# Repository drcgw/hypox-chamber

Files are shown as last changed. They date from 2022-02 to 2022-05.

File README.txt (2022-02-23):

Initial Raspberry Pi 4 set up

Using the Raspberry Pi OS installer (https://www.raspberrypi.com/software/) and a blank microSD card (128 GB Recommended) write the raspbian OS onto the SD card. Under the "operating system" menu select "Raspberry Pi OS (other)" and select "Raspberry Pi OS Full (32-bit)". Once the operating system is written to the SD card placed into Raspberry Pi. 

Once initial setup is completed go to terminal (Ctrl + T) and run the following codes:
    sudo apt update
    sudo apt full-upgrade

Next step is to download WiringPi:
    sudo apt-get update
    git clone https://github.com/WiringPi/WiringPi
    cd WiringPi
    ./build

Once these applications have been downloaded check the version by running:
    gpio -v
    gpio readall

System settings also need to be modified. Go to the configuration settings by using the following code: 
    sudo raspi-config
    
Under "Interfacing Options" insure that camera, SSH, VNC, SPI, I2C, Serial, and Remote GPIO are all enabled
System will require a reboot following these changes. The final items that need to be installed are all the python packaged and adafruit system requirements for CircuitPython. Tutorials and information can be found on Adafruit's website (https://learn.adafruit.com/welcome-to-circuitpython).
    sudo pip3 install adafruit-circuitpython-ads1x15
    sudo pip3 install adafruit-circuitpython-bme280
    sudo pip3 install adafruit-circuitpython-mcp9808
    sudo pip3 install adafruit-circuitpython-ccs811
    sudo pip3 install adafruit-circuitpython-bh1750

Once all the background files have been downloaded the github library can be downloaded using 
    wget https://github.com/drcgw/hypox-chamber.git

Unpack the files by unzipping and move RunChamber.sh file to the desktop.

Files can also be run manually through the terminal. Move the "PythonScript/" folder under "Documents/". If running manually before each run create a folder under "Documents/" with the following naming format "YYYY-MM-DD-Exposure/". Once inside this directory create: "FinalData/", "RawData/", "Calibration/" & "ImageCapture/" folders. After these folders have been created the exposure code can be run using the follow codes in the terminal. 
	cd Documents/PythonCodes/
	python3 2022-02-15-HC2000.py

If running it manually make sure that the most recent code has been installed and change the name in the second line of the above code to match the most recent copy of the .py script under the PythonCodes folder.

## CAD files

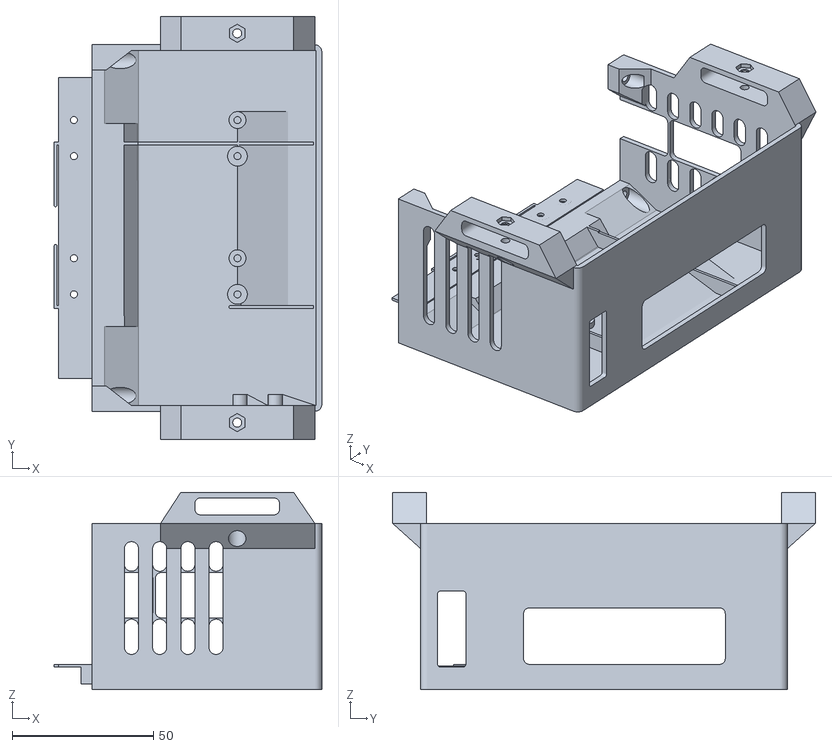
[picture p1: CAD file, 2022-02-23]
3D_Files/RH501_PiHolder_Left.stl
94.9 x 150.0 x 70.0

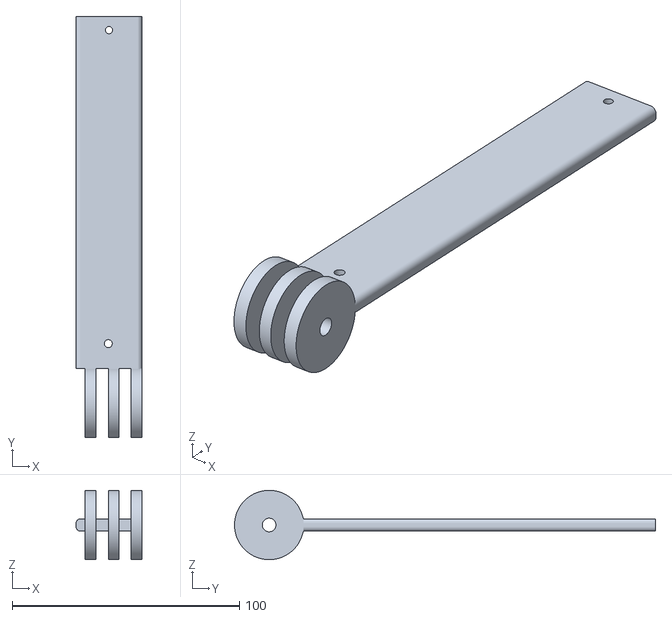
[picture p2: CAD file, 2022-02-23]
3D_Files/RH500_MountingRod.stl
29.0 x 185.3 x 30.5

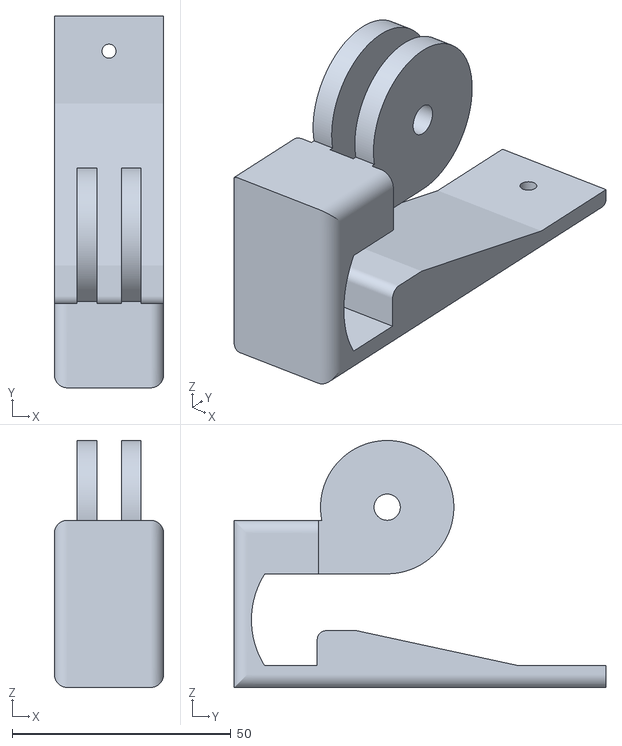
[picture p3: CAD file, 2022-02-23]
3D_Files/RH500_Clip.stl
25.0 x 85.0 x 56.5

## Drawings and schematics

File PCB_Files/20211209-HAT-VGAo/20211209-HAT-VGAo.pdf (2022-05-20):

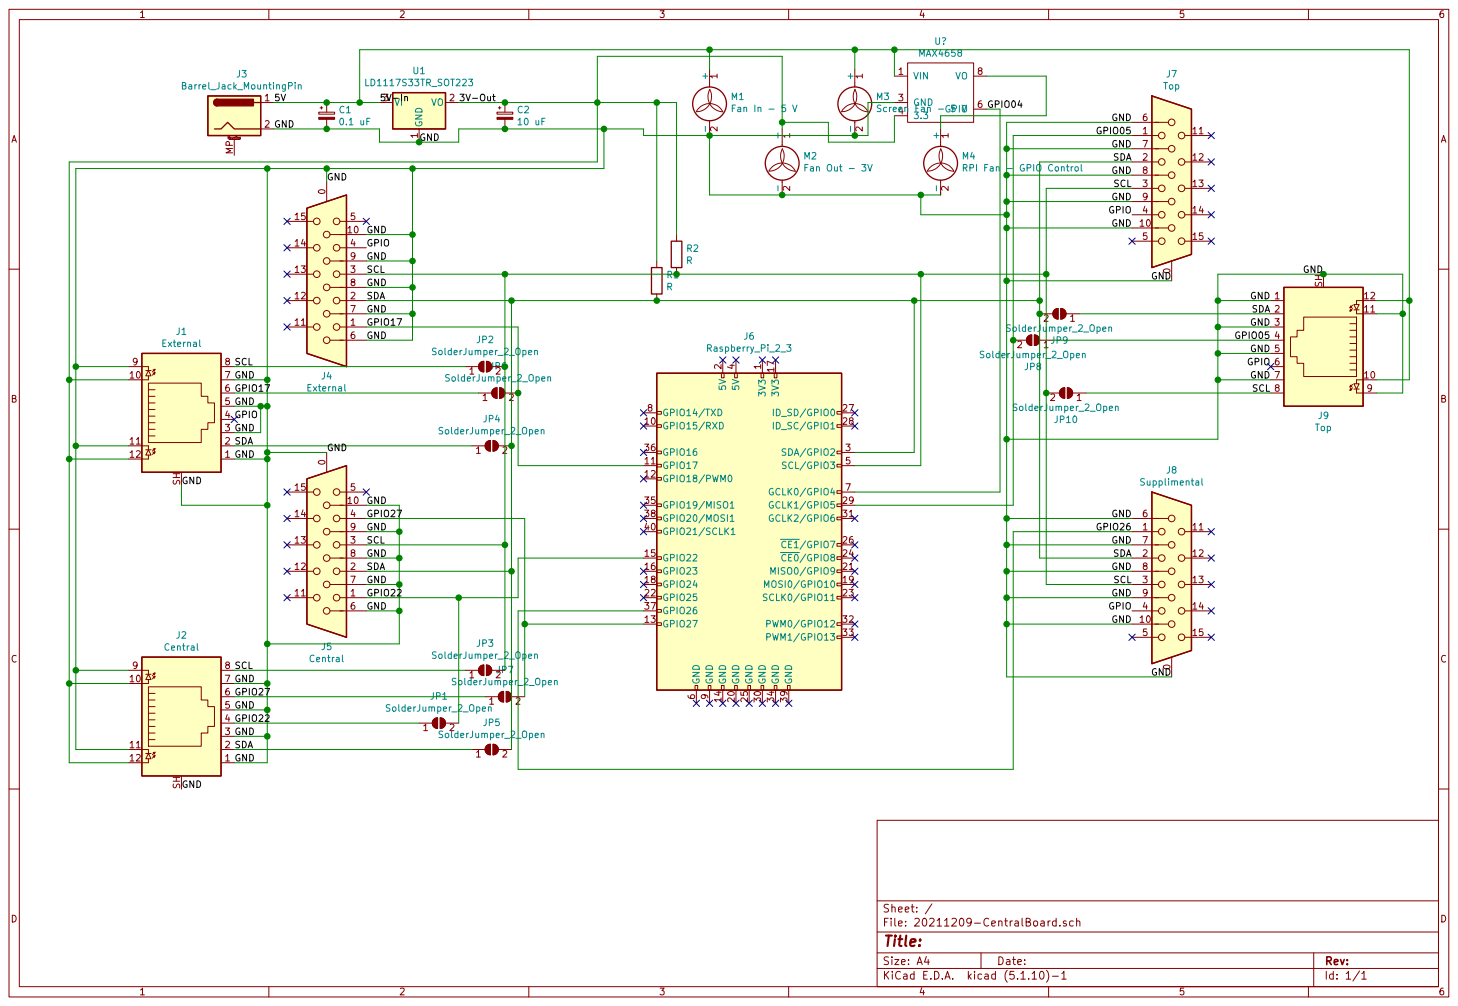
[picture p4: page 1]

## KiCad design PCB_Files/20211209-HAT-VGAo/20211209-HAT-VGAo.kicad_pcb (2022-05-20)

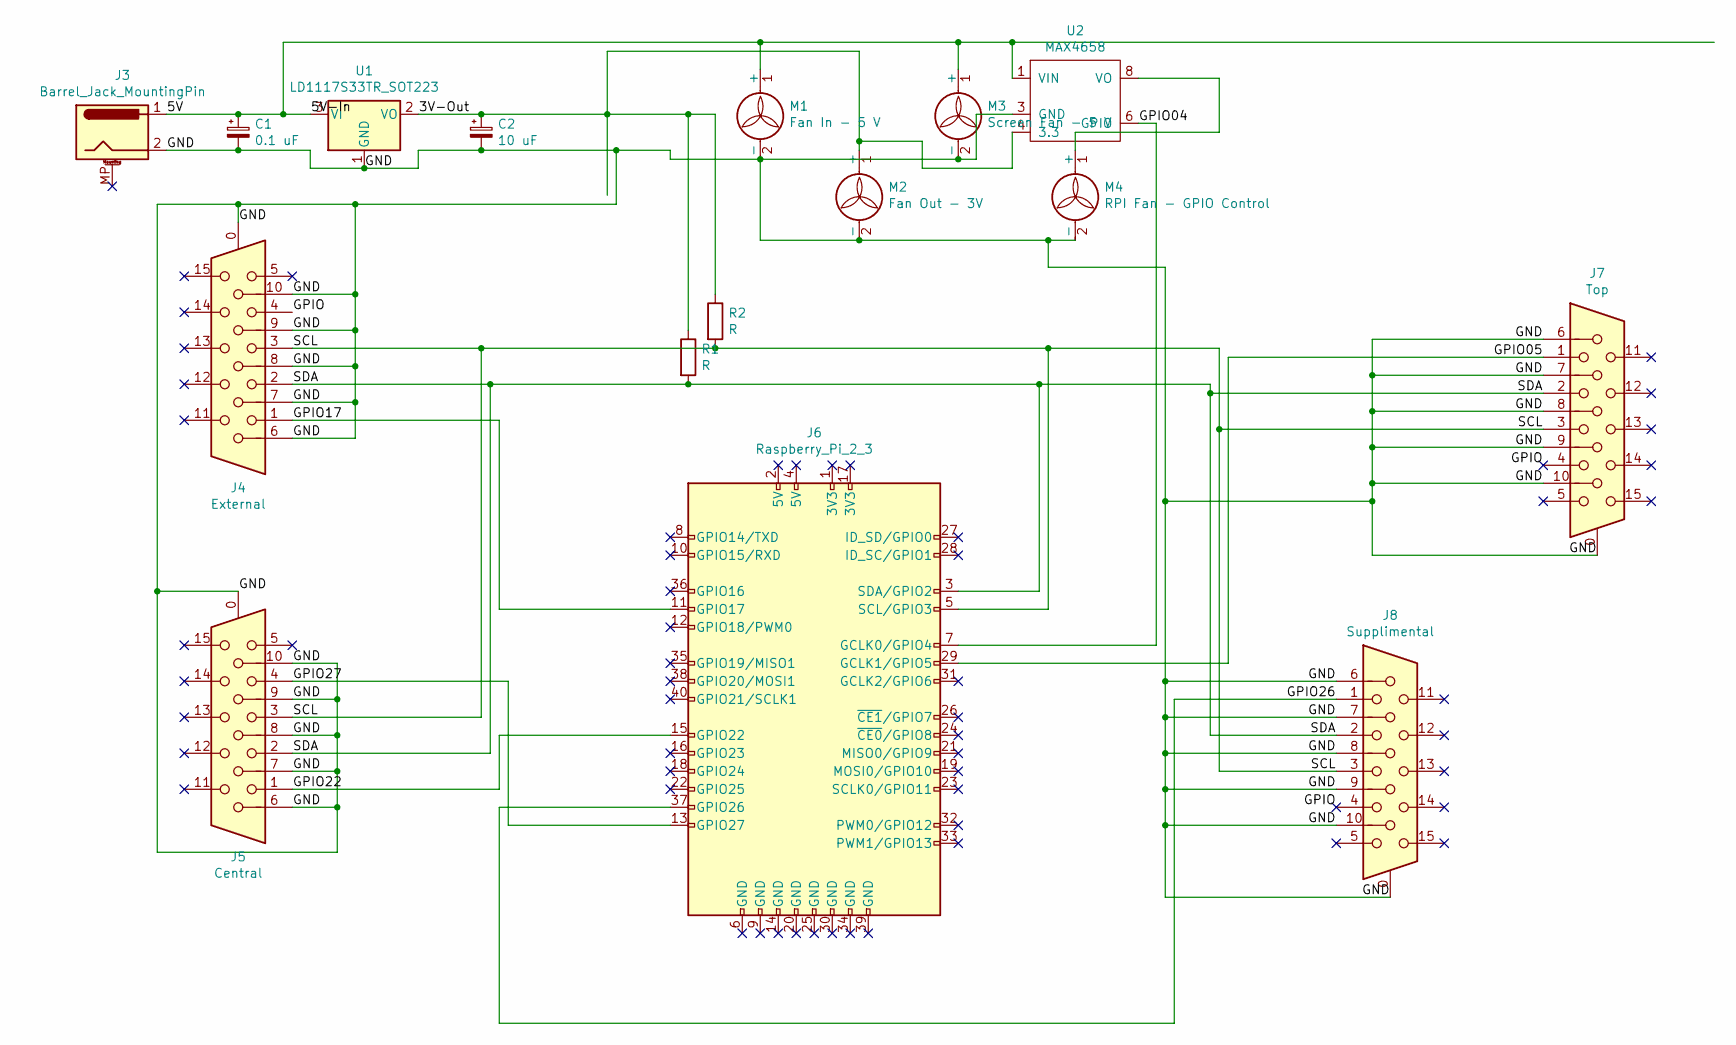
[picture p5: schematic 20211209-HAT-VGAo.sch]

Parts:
C1: 0.1 uF; C_Disc_D3.0mm_W2.0mm_P2.50mm
C2: 10 uF; CP_Radial_D5.0mm_P2.50mm
J3: Barrel_Jack_MountingPin; BarrelJack_Horizontal_w_MP
J4: External; DSUB-15-HD-Female-Horixonal_P2.29x2.54mm_EdgePinOffset8.35m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
J5: Central; DSUB-15-HD-Female-Horixonal_P2.29x2.54mm_EdgePinOffset8.35m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
J6: Raspberry_Pi_2_3; Raspberry_Pi_GPIO_ScrewAttachment
J7: Top; DSUB-15-HD-Female-Horixonal_P2.29x2.54mm_EdgePinOffset8.35m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
J8: Supplimental; DSUB-15-HD-Female-Horixonal_P2.29x2.54mm_EdgePinOffset8.35m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
M1: Fan In - 5 V; PinHeader_1x02_P2.54mm_Vertical (2)
M2: Fan Out - 3V; PinHeader_1x02_P2.54mm_Vertical (2)
M3: Screen Fan - 5 V; PinHeader_1x02_P2.54mm_Vertical (2)
M4: RPI Fan - GPIO Control; RPi_Fan_30mm_24mm
R1, R2: R; R_Axial_DIN0204_L3.6mm_D1.6mm_P7.62mm_Horizontal
U1: LD1117S33TR_SOT223; 3.3V_Regulator
U2: MAX4658

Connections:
/3V-Out: C2.1, M2.1 (+), R1.1, R2.1, U1.2 (VO), U2.4 (3.3)
/5V: C1.1, J3.1, M1.1 (+), M3.1 (+), U1.3 (VI), U2.1 (VIN)
/GND: C1.2, C2.2, J3.2, J4.0, J4.6, J4.7, J4.8, J4.9, J4.10, J5.0, J5.6, J5.7, J5.8, J5.9, J5.10, J7.0, J7.6, J7.7, J7.8, J7.9, J7.10, J8.0, J8.6, J8.7, J8.8, J8.9, J8.10, M1.2 (-), M2.2 (-), M3.2 (-), M4.2 (-), U1.1 (GND), U2.3 (GND)
/GPIO: J4.4, J7.4, J8.4
/GPIO04: J6.7 (GCLK0/GPIO4), U2.6 (GPIO)
/GPIO05: J6.29 (GCLK1/GPIO5), J7.1
/GPIO17: J4.1, J6.11 (GPIO17)
/GPIO22: J5.1, J6.15 (GPIO22)
/GPIO26: J6.37 (GPIO26), J8.1
/GPIO27: J5.4, J6.13 (GPIO27)
/SCL: J4.3, J5.3, J6.5 (SCL/GPIO3), J7.3, J8.3, R2.2
/SDA: J4.2, J5.2, J6.3 (SDA/GPIO2), J7.2, J8.2, R1.2
unnamed: M4.1 (+), U2.8 (VO)

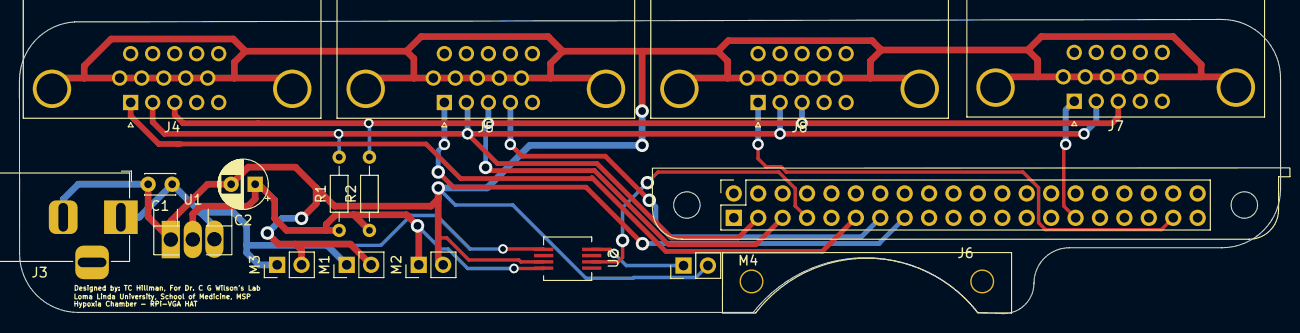
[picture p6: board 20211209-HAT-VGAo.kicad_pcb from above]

Board: 2 copper layers, 131.2 x 30.6 mm, 16 parts (0 on the bottom side), 13 nets.

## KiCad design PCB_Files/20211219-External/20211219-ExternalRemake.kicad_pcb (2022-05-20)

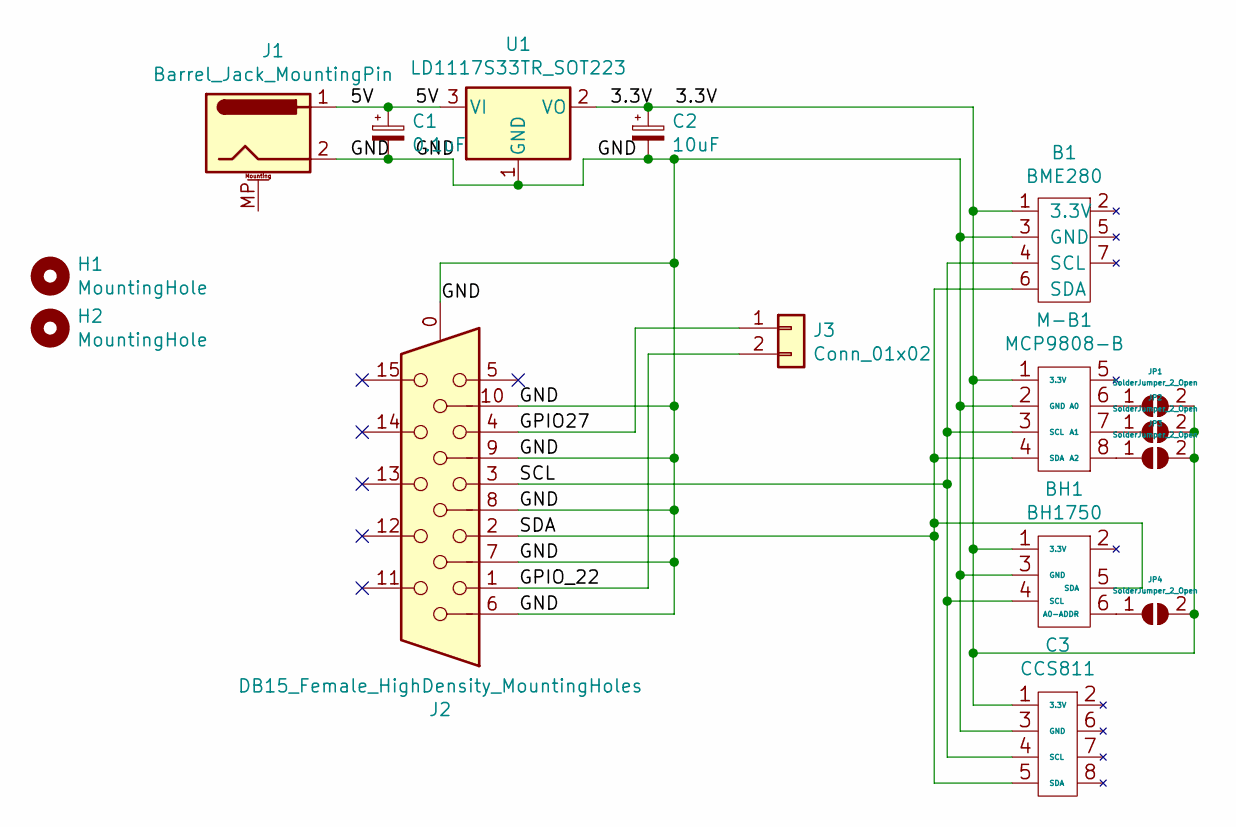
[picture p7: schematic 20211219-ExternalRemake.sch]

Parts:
B1: BME280; PinHeader_1x07_P2.54mm_Vertical
BH1: BH1750; PinHeader_1x06_P2.54mm_Vertical
C1: 0.1uF; C_Disc_D5.1mm_W3.2mm_P5.00mm
C2: 10uF; CP_Radial_D6.3mm_P2.50mm
C3: CCS811; PinHeader_1x08_P2.54mm_Vertical
H1, H2: MountingHole; MountingHole_2.7mm_M2.5_DIN965_Pad_TopBottom
J1: Barrel_Jack_MountingPin; BarrelJack_Horizontal_w_MP
J2: DB15_Female_HighDensity_MountingHoles; DSUB-15-HD-Female-Horixonal_P2.29x2.54mm_EdgePinOffset8.35m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
J3: Conn_01x02; PinHeader_1x02_P2.54mm_Vertical
JP1, JP2, JP3, JP4: SolderJumper_2_Open; SolderJumper-2_P1.3mm_Open_TrianglePad1.0x1.5mm
M-B1: MCP9808-B; PinHeader_1x08_P2.54mm_Vertical
U1: LD1117S33TR_SOT223; 3.3V_Regulator

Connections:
/3.3V: B1.1 (3.3V), BH1.1 (3.3V), C2.1, C3.1 (3.3V), JP1.2 (B), JP2.2 (B), JP3.2 (B), JP4.2 (B), M-B1.1 (3.3V), U1.2 (VO)
/5V: C1.1, J1.1, U1.3 (VI)
/GND: B1.3 (GND), BH1.3 (GND), C1.2, C2.2, C3.3 (GND), J1.2, J2.0, J2.6, J2.7, J2.8, J2.9, J2.10, M-B1.2 (GND), U1.1 (GND)
/GPIO27: J2.4, J3.1
/GPIO_22: J2.1, J3.2
/SCL: B1.4 (SCL), BH1.4 (SCL), C3.4 (SCL), J2.3, M-B1.3 (SCL)
/SDA: B1.6 (SDA), BH1.5 (SDA), C3.5 (SDA), J2.2, M-B1.4 (SDA)
unnamed: BH1.6 (A0-ADDR), JP4.1 (A)
unnamed: JP1.1 (A), M-B1.6 (A0)
unnamed: JP2.1 (A), M-B1.7 (A1)
unnamed: JP3.1 (A), M-B1.8 (A2)

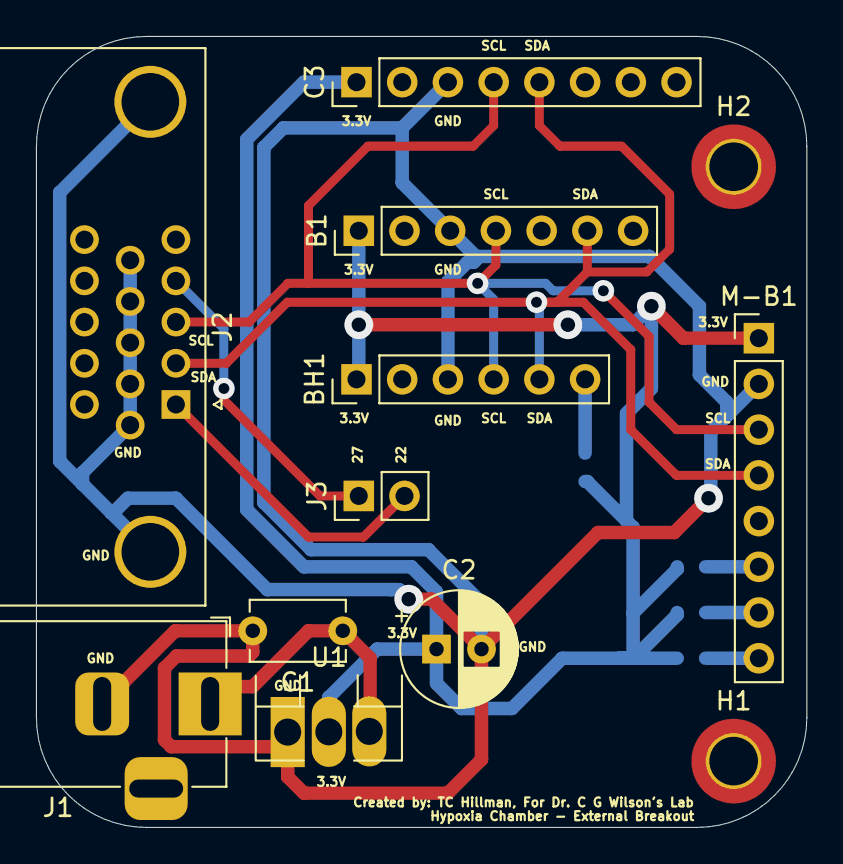
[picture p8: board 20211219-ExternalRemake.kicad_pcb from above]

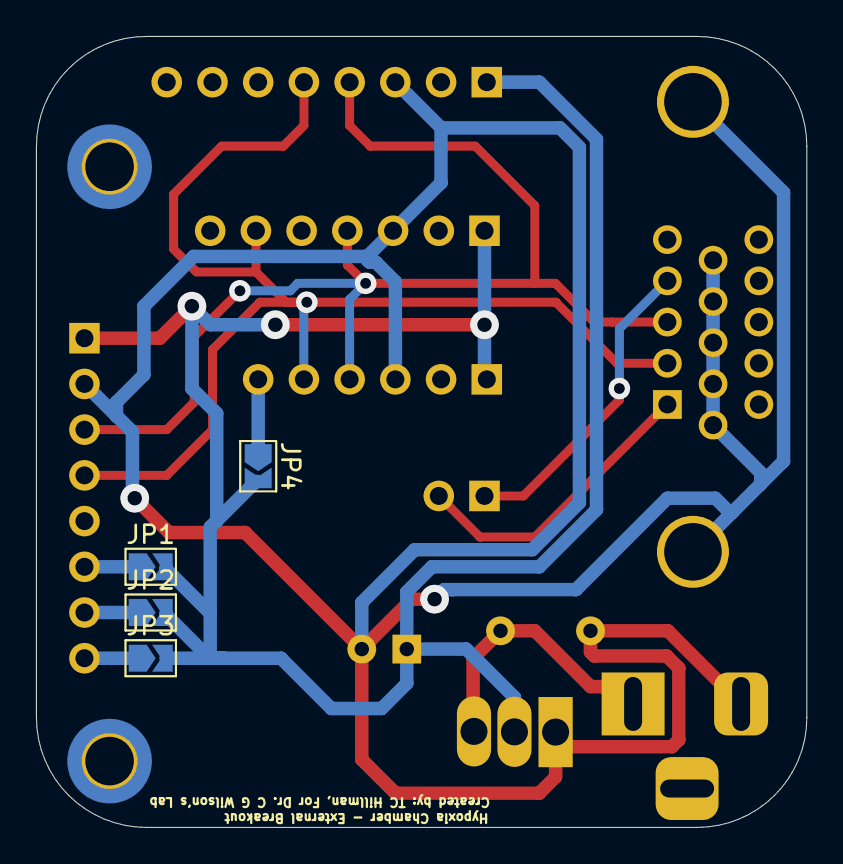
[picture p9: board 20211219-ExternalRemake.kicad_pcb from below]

Board: 2 copper layers, 42.8 x 43.9 mm, 16 parts (4 on the bottom side), 11 nets.

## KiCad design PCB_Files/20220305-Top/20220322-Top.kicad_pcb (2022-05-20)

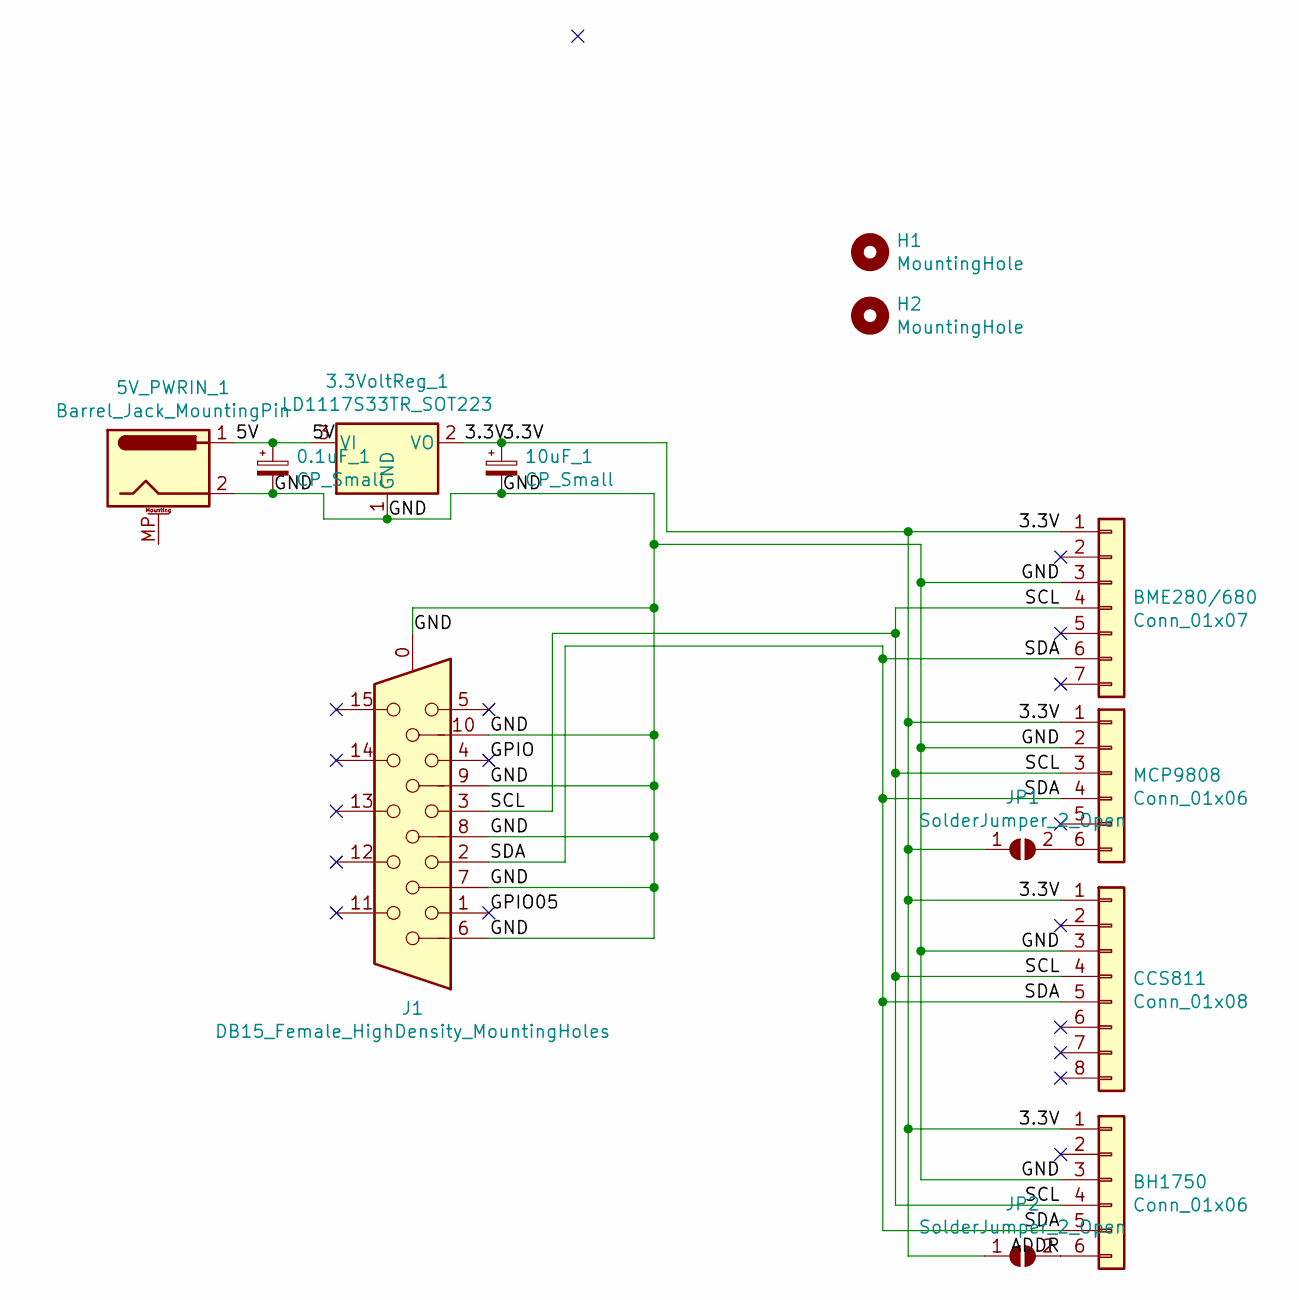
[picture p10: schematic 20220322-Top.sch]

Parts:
0.1uF_1: CP_Small; C_Disc_0.1uF_D3.8mm_W2.6mm_P2.50mm
3.3VoltReg_1: LD1117S33TR_SOT223; 3.3V_Regulator
5V_PWRIN_1: Barrel_Jack_MountingPin; BarrelJack_Horizontal_w_MP
10uF_1: CP_Small; CP_10uF_Radial_D6.3mm_P2.50mm
BH1750: Conn_01x06; PinHeader_1x06_P2.54mm_Vertical
BME280/680: Conn_01x07; PinHeader_1x07_P2.54mm_Vertical
CCS811: Conn_01x08; PinHeader_1x08_P2.54mm_Vertical
H1, H2: MountingHole; MountingHole_2.5mm_Pad_TopBottom
J1: DB15_Female_HighDensity_MountingHoles; DSUB-15-HD-Female-Horixonal_P2.29x2.54mm_EdgePinOffset8.35m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
JP1, JP2: SolderJumper_2_Open; SolderJumper-2_P1.3mm_Open_TrianglePad1.0x1.5mm
MCP9808: Conn_01x06; PinHeader_1x06_P2.54mm_Vertical

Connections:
/3.3V: 3.3VoltReg_1.2 (VO), 10uF_1.1, BH1750.1, BME280/680.1, CCS811.1, JP1.1 (A), JP2.1 (A), MCP9808.1
/5V: 0.1uF_1.1, 3.3VoltReg_1.3 (VI), 5V_PWRIN_1.1
/ADDR: BH1750.6, JP2.2 (B)
/GND: 0.1uF_1.2, 3.3VoltReg_1.1 (GND), 5V_PWRIN_1.2, 10uF_1.2, BH1750.3, BME280/680.3, CCS811.3, J1.0, J1.6, J1.7, J1.8, J1.9, J1.10, MCP9808.2
/GPIO: J1.4
/GPIO05: J1.1
/SCL: BH1750.4, BME280/680.4, CCS811.4, J1.3, MCP9808.3
/SDA: BH1750.5, BME280/680.6, CCS811.5, J1.2, MCP9808.4
unnamed: JP1.2 (B), MCP9808.6

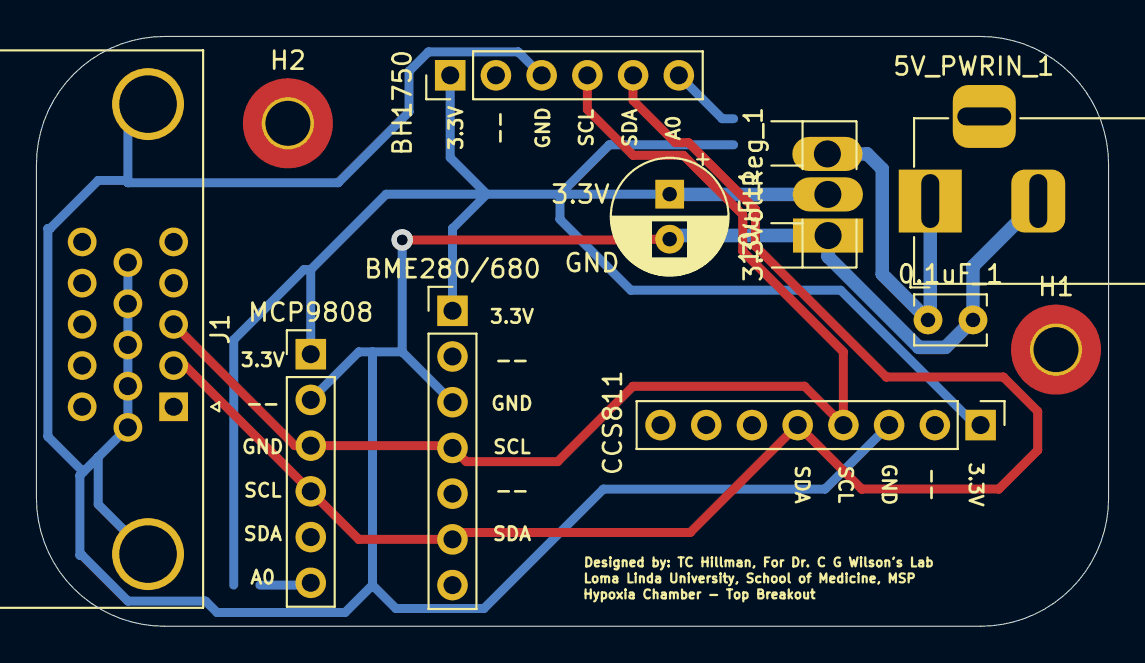
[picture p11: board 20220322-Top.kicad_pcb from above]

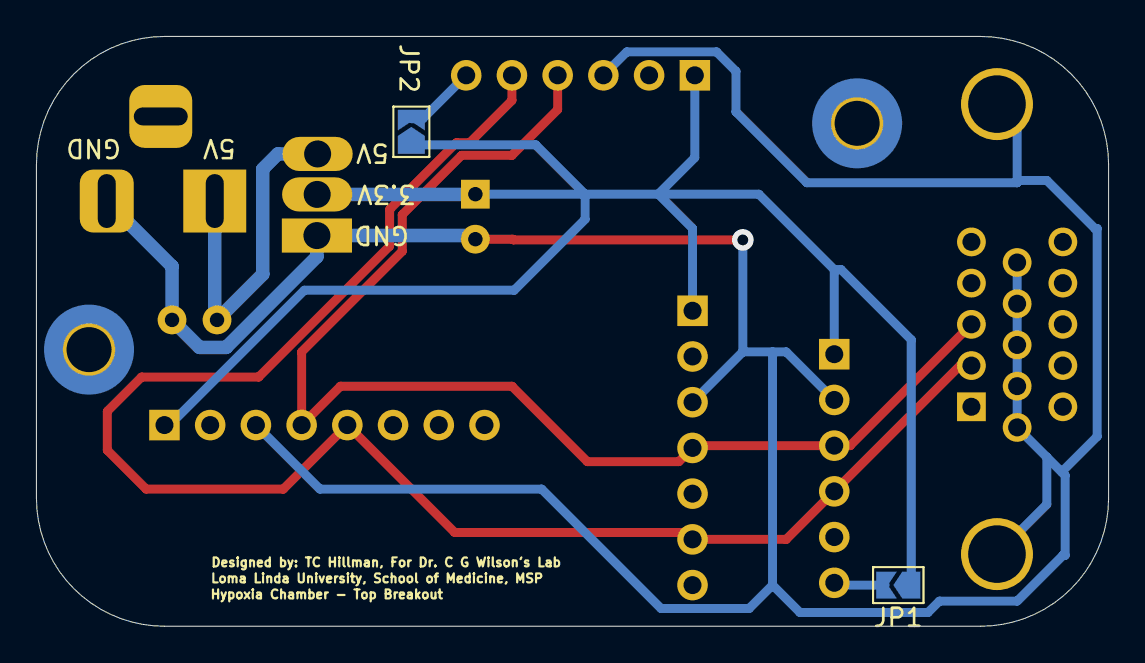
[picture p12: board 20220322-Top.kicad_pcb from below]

Board: 2 copper layers, 59.6 x 32.8 mm, 13 parts (2 on the bottom side), 7 nets.

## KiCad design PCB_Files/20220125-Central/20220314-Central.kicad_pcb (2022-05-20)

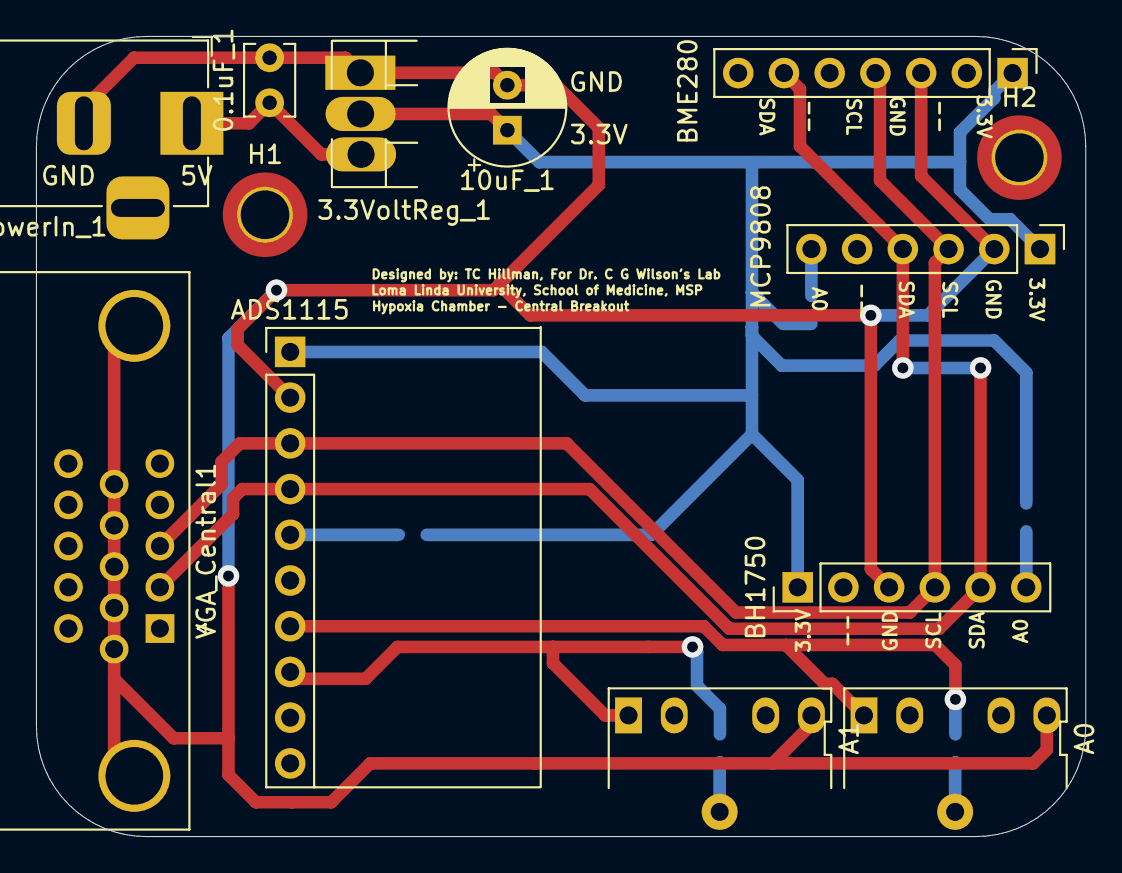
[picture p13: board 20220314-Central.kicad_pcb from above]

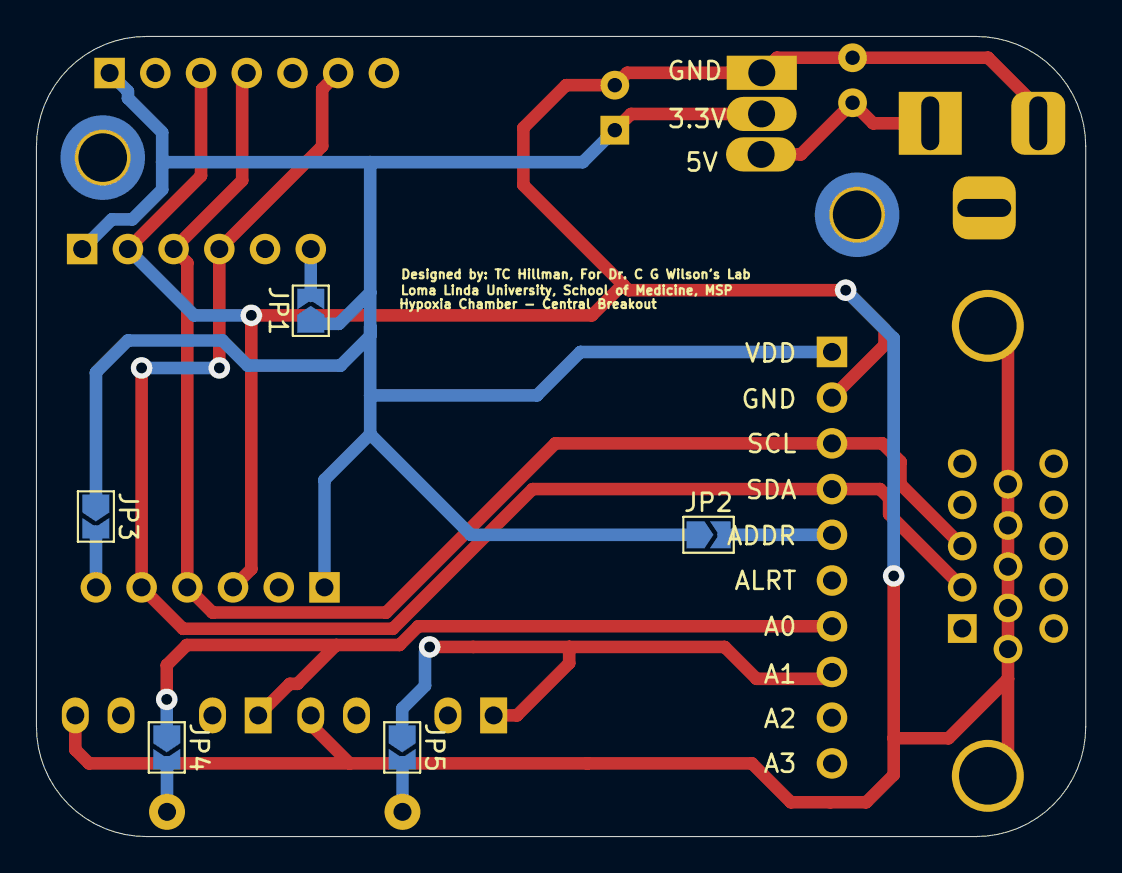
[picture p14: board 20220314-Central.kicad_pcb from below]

Board: 2 copper layers, 58.3 x 44.5 mm, 18 parts (5 on the bottom side), 11 nets.

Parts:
0.1uF_1: CP_Small; C_Disc_0.1uF_D3.8mm_W2.6mm_P2.50mm
3.3VoltReg_1: LD1117S33TR_SOT223; 3.3V_Regulator
10uF_1: CP_Small; CP_10uF_Radial_D6.3mm_P2.50mm
A0, A1: AudioJack3; 20220314-UniversalAux
ADS1115: Conn_01x10; ADS1115
BH1750: Conn_01x06; PinHeader_1x06_P2.54mm_Vertical
BME280: Conn_01x07; PinHeader_1x07_P2.54mm_Vertical
H1, H2: MountingHole; MountingHole_2.7mm_M2.5_DIN965_Pad_TopBottom
JP1, JP2, JP3, JP4, JP5: SolderJumper_2_Open; SolderJumper-2_P1.3mm_Open_TrianglePad1.0x1.5mm
MCP9808: Conn_01x06; PinHeader_1x06_P2.54mm_Vertical
PowerIn_1: Barrel_Jack_MountingPin; BarrelJack_Horizontal_w_MP
VGA_Central1: DB15_Female_HighDensity_MountingHoles; DSUB-15-HD-Female-Horixonal_P2.29x2.54mm_EdgePinOffset8.35m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

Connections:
/3.3VIn: 3.3VoltReg_1.2, 10uF_1.1, ADS1115.1, BH1750.1, BME280.1, JP1.1, JP2.1, JP3.1, MCP9808.1
/5v: 0.1uF_1.1, 3.3VoltReg_1.3, PowerIn_1.1
/A0: A0.S, ADS1115.7, JP4.1
/A1: A1.S, ADS1115.8, JP5.1
/ADDR: ADS1115.5, BH1750.6, JP2.2, JP3.2
/Ad0: JP1.2, MCP9808.6
/GND: 0.1uF_1.2, 3.3VoltReg_1.1, 10uF_1.2, A0.T, A1.T, ADS1115.2, BH1750.3, BME280.3, MCP9808.2, PowerIn_1.2, VGA_Central1.0, VGA_Central1.6, VGA_Central1.7, VGA_Central1.8, VGA_Central1.9, VGA_Central1.10
/SCL: ADS1115.3, BH1750.4, BME280.4, MCP9808.3, VGA_Central1.3
/SDA: ADS1115.4, BH1750.5, BME280.6, MCP9808.4, VGA_Central1.2
unnamed: A0.R, JP4.2
unnamed: A1.R, JP5.2

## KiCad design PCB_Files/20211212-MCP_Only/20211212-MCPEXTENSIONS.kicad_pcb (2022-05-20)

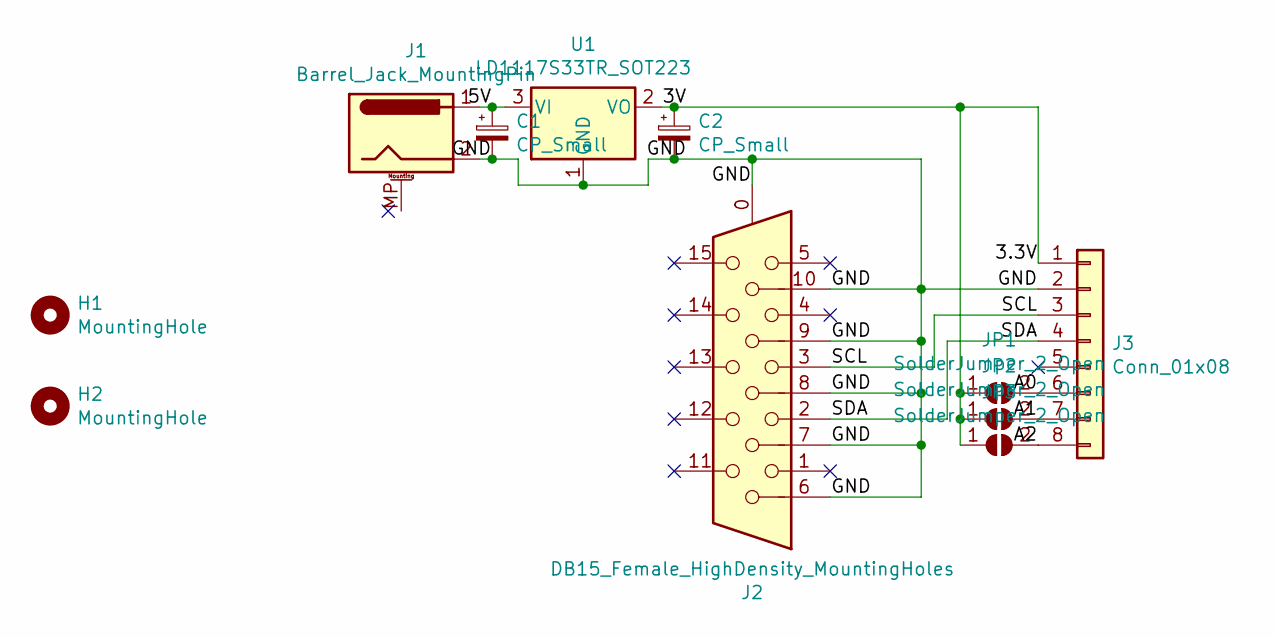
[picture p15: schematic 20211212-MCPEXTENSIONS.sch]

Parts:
C1: CP_Small; C_Disc_0.1uF_D3.8mm_W2.6mm_P2.50mm
C2: CP_Small; CP_10uF_Radial_D6.3mm_P2.50mm
H1, H2: MountingHole; MountingHole_2.5mm_Pad_TopBottom
J1: Barrel_Jack_MountingPin; BarrelJack_Horizontal_w_MP
J2: DB15_Female_HighDensity_MountingHoles; DSUB-15-HD-Female-Horixonal_P2.29x2.54mm_EdgePinOffset8.35m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
J3: Conn_01x08; PinHeader_1x08_P2.54mm_Vertical
JP1, JP2, JP3: SolderJumper_2_Open; SolderJumper-2_P1.3mm_Open_TrianglePad1.0x1.5mm (2)
U1: LD1117S33TR_SOT223; 3.3V_Regulator

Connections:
/3.3V: C2.1, J3.1, JP1.1 (A), JP2.1 (A), JP3.1 (A), U1.2 (VO)
/5V: C1.1, J1.1, U1.3 (VI)
/A0: J3.6, JP1.2 (B)
/A1: J3.7, JP2.2 (B)
/A2: J3.8, JP3.2 (B)
/GND: C1.2, C2.2, J1.2, J2.0, J2.6, J2.7, J2.8, J2.9, J2.10, J3.2, U1.1 (GND)
/SCL: J2.3, J3.3
/SDA: J2.2, J3.4

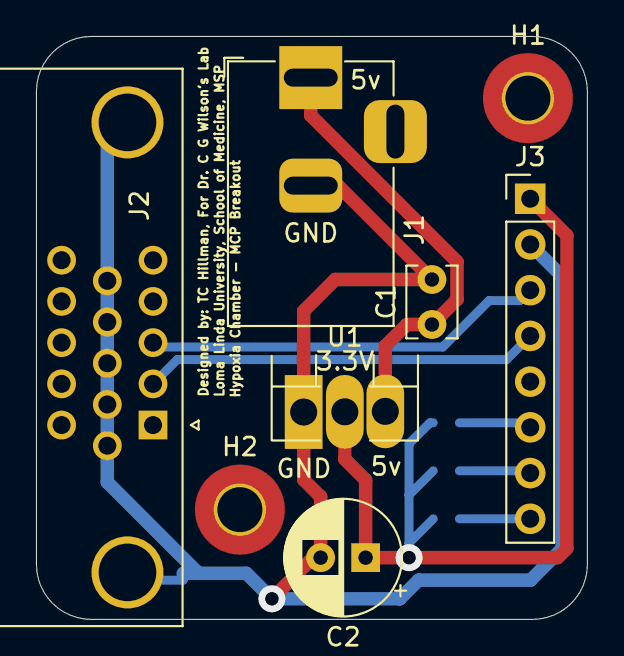
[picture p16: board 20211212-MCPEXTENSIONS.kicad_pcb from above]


Board: 2 copper layers, 30.6 x 32.4 mm, 11 parts (3 on the bottom side), 8 nets.

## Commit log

2022-02-22 Initial addition of files and folder for data collection. Files getting prepared for push to github repository https://github.com/drcgw/hypox-chamber.git.
2022-02-23 Addition of 3D design files to git hub library, currently only the Raspberry Pi holder is included in these files. Additional flies for board mounting is still in design.
    [RH500_Clip.stl, RH500_MountingRod.stl, RH501_PiHolder_Left.stl]
